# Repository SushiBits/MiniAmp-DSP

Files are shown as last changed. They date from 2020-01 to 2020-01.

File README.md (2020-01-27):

# MiniAmp DSP

Miniature Audio Amplifier with a DSP inside.

eUPID: `M2AUv3-AMP4268`

## Specifications

* Power input: DC 9-24V 6W, center positive barrel jack.
* Signal input: Unbalanced consumer line level, 3.5mm TRS jack.
* Outputs:
  * Left and Right speakers: balanced 6W class D output, screw terminals.
  * Center speaker: balanced 1W class AB output, screw terminals.
  * Subwoofer: Consumer line level, RCA coaxial.
  * Headphone: Unbalanced 6W class D output, 3.5mm TRS jack. The prescense of a
    headphone disables all other outputs.
* DSP: Analog Devices AD1701 SigmaDSP.

## Programming the DSP

This DSP is programmed using [Analog Devices SigmaStudio][1]. You need a USBi,
for example the [SigmaLink USBi][2], to program the devce.

[1]: https://www.analog.com/en/design-center/evaluation-hardware-and-software/software/ss_sigst_02.html
[2]: https://github.com/freeDSP/SigmaLink-USBi

## License & Contacts

Copyright &copy; 2019-2020 Max Chan. All rights reserved.

This project is licensed under [3-clause BSD license](LICENSE.md).

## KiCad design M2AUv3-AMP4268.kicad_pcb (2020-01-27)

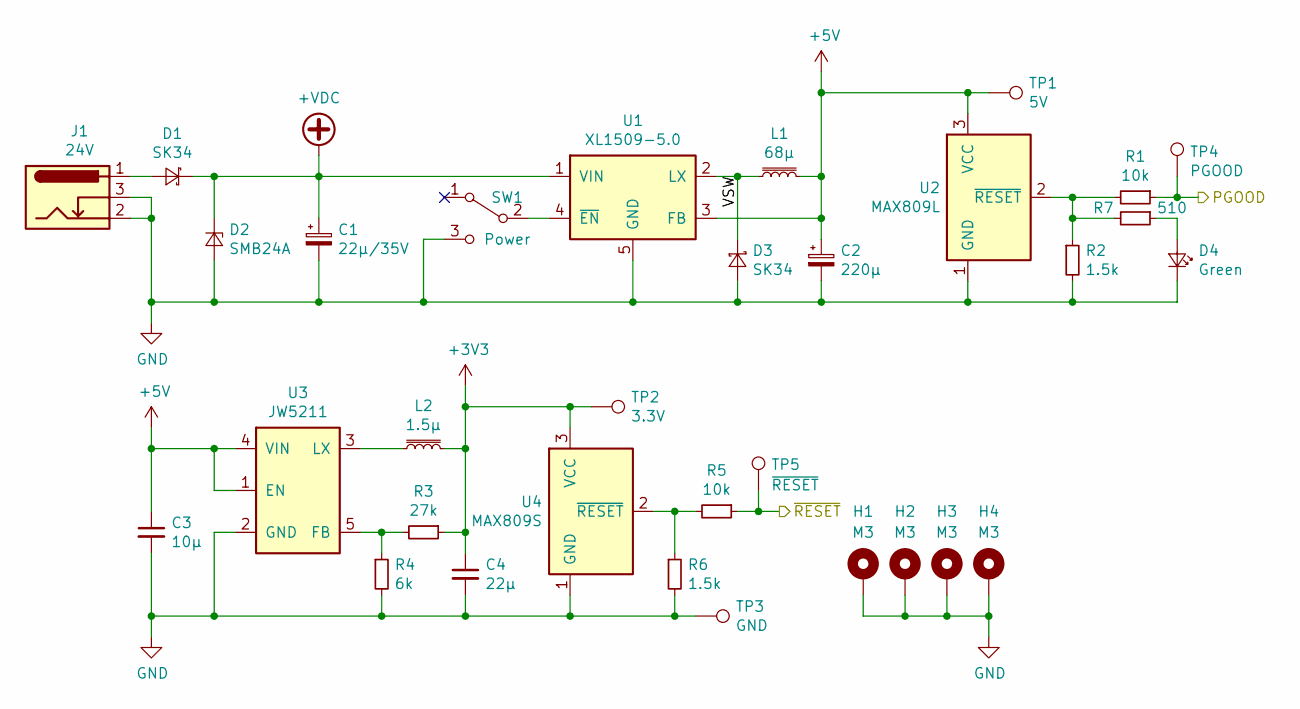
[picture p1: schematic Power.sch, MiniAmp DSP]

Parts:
C1: 22µ/35V; CP_Elec_6.3x5.4
C2: 220µ; CP_Elec_6.3x5.4
C3: 10µ; C_0805_2012Metric_Pad1.15x1.40mm_HandSolder
C4: 22µ; C_0805_2012Metric_Pad1.15x1.40mm_HandSolder
D1, D3: SK34; D_SMB
D2: SMB24A; D_SMB
D4: Green; LED_1206_3216Metric_Pad1.42x1.75mm_HandSolder
H1, H2, H3, H4: M3; MountingHole_3.2mm_M3_Pad_Via
J1: 24V; BarrelJack_Wuerth_6941xx301002
L1: 68µ; L_Taiyo-Yuden_NR-60xx_HandSoldering
L2: 1.5µ; L_0806_2016Metric_Pad1.15x1.80mm_HandSolder
R1, R5: 10k; R_0603_1608Metric_Pad1.05x0.95mm_HandSolder
R2, R6: 1.5k; R_0603_1608Metric_Pad1.05x0.95mm_HandSolder
R3: 27k; R_0603_1608Metric_Pad1.05x0.95mm_HandSolder
R4: 6k; R_0603_1608Metric_Pad1.05x0.95mm_HandSolder
R7: 510; R_0603_1608Metric_Pad1.05x0.95mm_HandSolder
SW1: Power; SW_SPDT_PCM12
TP1: 5V; TestPoint_Loop_D2.54mm_Drill1.5mm_Beaded
TP2: 3.3V; TestPoint_Loop_D2.54mm_Drill1.5mm_Beaded
TP3: GND; TestPoint_Loop_D2.54mm_Drill1.5mm_Beaded
TP4: PGOOD; TestPoint_Loop_D2.54mm_Drill1.5mm_Beaded
TP5: ~RESET; TestPoint_Loop_D2.54mm_Drill1.5mm_Beaded
U1: XL1509-5.0; SOIC-8_3.9x4.9mm_P1.27mm
U2: MAX809L; SOT-23
U3: JW5211; SOT-23-5
U4: MAX809S; SOT-23

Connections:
+3V3: C4.1, L2.2, R3.1, TP2.1, U4.3 (VCC); also elsewhere on the board
+5V: C2.1, C3.1, L1.2, TP1.1, U1.3 (FB), U2.3 (VCC), U3.1 (EN), U3.4 (VIN); also elsewhere on the board
+VDC: C1.1, D1.1 (K), D2.1 (K), U1.1 (VIN)
/DSP/~RESET: R5.1, TP5.1; also elsewhere on the board
/PGOOD: R1.1, TP4.1; also elsewhere on the board
/Power Delivery/VSW: D3.1 (K), L1.1, U1.2 (LX)
GND: C1.2, C2.2, C3.2, C4.2, D2.2 (A), D3.2 (A), D4.1 (K), H1.1, H2.1, H3.1, H4.1, J1.2, J1.3, R2.2, R4.2, R6.2, SW1.3 (C), TP3.1, U1.5 (GND), U1.6 (GND), U1.7 (GND), U1.8 (GND), U2.1 (GND), U3.2 (GND), U4.1 (GND); also elsewhere on the board
unnamed: D1.2 (A), J1.1
unnamed: D4.2 (A), R7.1
unnamed: L2.1, U3.3 (LX)
unnamed: R1.2, R2.1, R7.2, U2.2 (~RESET~)
unnamed: R3.2, R4.1, U3.5 (FB)
unnamed: R5.2, R6.1, U4.2 (~RESET~)
unnamed: SW1.2 (B), U1.4 (~EN)

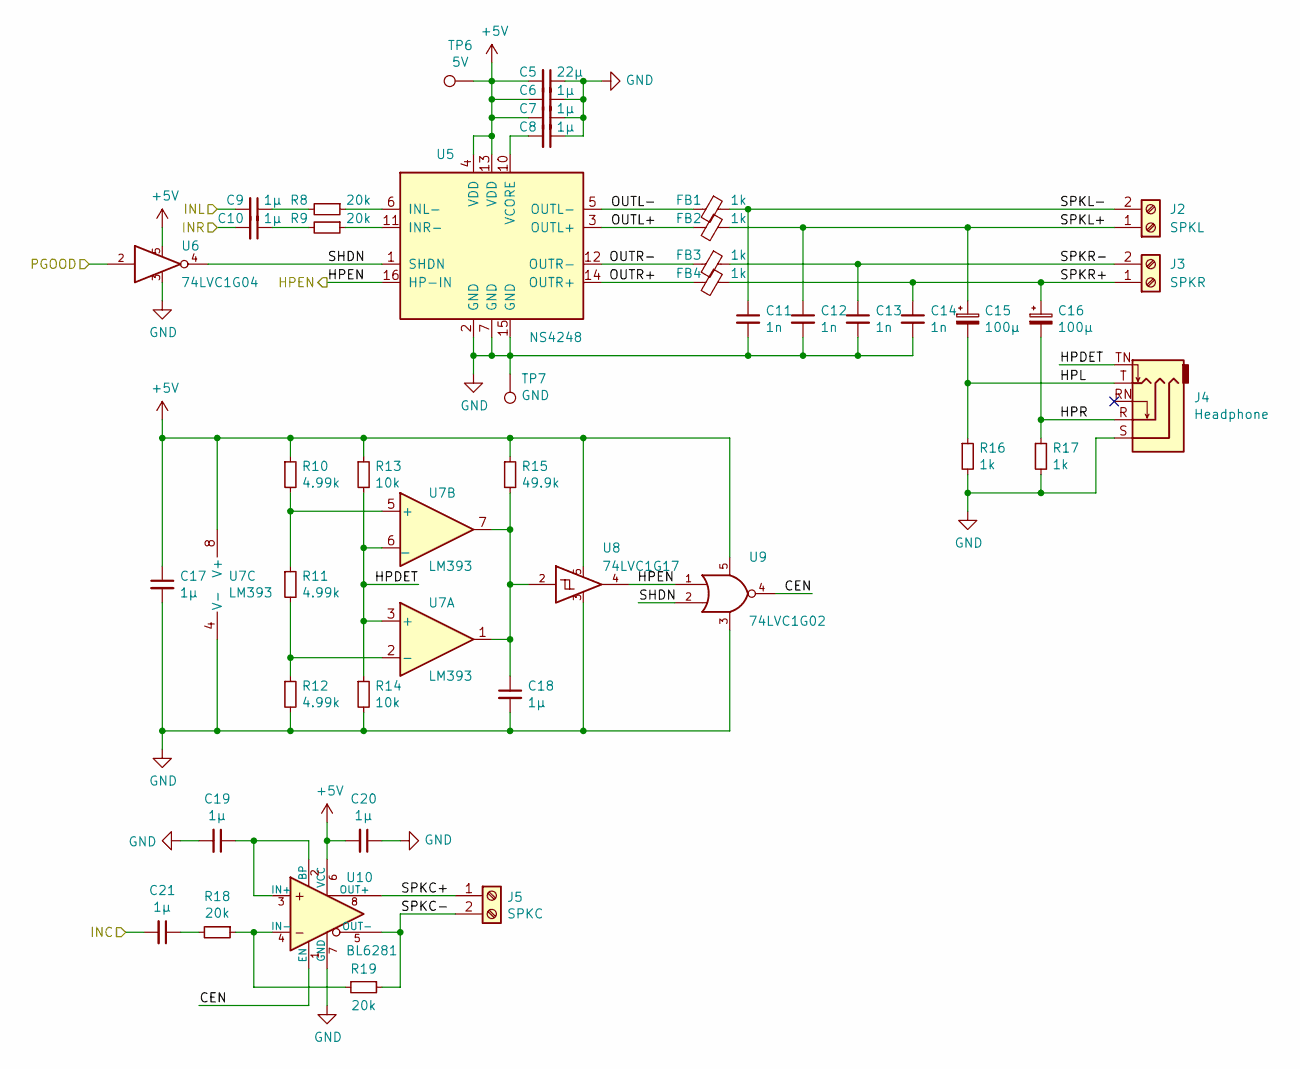
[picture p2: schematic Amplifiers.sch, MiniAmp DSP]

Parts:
C5: 22µ; C_0805_2012Metric_Pad1.15x1.40mm_HandSolder
C6, C7, C8, C9, C10, C17, C18, C19, C20, C21: 1µ; C_0603_1608Metric_Pad1.05x0.95mm_HandSolder
C11, C12, C13, C14: 1n; C_0603_1608Metric_Pad1.05x0.95mm_HandSolder
C15, C16: 100µ; CP_EIA-3528-21_Kemet-B_Pad1.50x2.35mm_HandSolder
FB1, FB2, FB3, FB4: 1k; L_0603_1608Metric_Pad1.05x0.95mm_HandSolder
J2: SPKL; TerminalBlock_Phoenix_MKDS-3-2-5.08_1x02_P5.08mm_Horizontal
J3: SPKR; TerminalBlock_Phoenix_MKDS-3-2-5.08_1x02_P5.08mm_Horizontal
J4: Headphone; Jack_3.5mm_Ledino_KB3SPRS_Horizontal
J5: SPKC; TerminalBlock_Phoenix_MKDS-3-2-5.08_1x02_P5.08mm_Horizontal
R8, R9, R18, R19: 20k; R_0603_1608Metric_Pad1.05x0.95mm_HandSolder
R10, R11, R12: 4.99k; R_0603_1608Metric_Pad1.05x0.95mm_HandSolder
R13, R14: 10k; R_0603_1608Metric_Pad1.05x0.95mm_HandSolder
R15: 49.9k; R_0603_1608Metric_Pad1.05x0.95mm_HandSolder
R16, R17: 1k; R_0603_1608Metric_Pad1.05x0.95mm_HandSolder
TP6: 5V; TestPoint_Loop_D2.54mm_Drill1.5mm_Beaded
TP7: GND; TestPoint_Loop_D2.54mm_Drill1.5mm_Beaded
U5: NS4248; SOIC-16_3.9x9.9mm_P1.27mm
U6: 74LVC1G04; SOT-23-5
U7: LM393; SOIC-8_3.9x4.9mm_P1.27mm
U8: 74LVC1G17; SOT-23-5
U9: 74LVC1G02; SOT-23-5
U10: BL6281; SOIC-8_3.9x4.9mm_P1.27mm

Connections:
+5V: C5.2, C6.2, C7.2, C17.1, C20.2, R10.1, R13.1, R15.1, TP6.1, U5.4 (VDD), U5.13 (VDD), U6.5, U7.8 (V+), U8.5, U9.5 (VCC), U10.6 (VCC); also elsewhere on the board
/Amplified Output/CEN: U9.4, U10.1 (EN)
/Amplified Output/HPDET: J4.TN, R13.2, R14.1, U7.3 (+), U7.6 (_)
/Amplified Output/HPEN: U5.16 (HP-IN), U8.4, U9.1; also elsewhere on the board
/Amplified Output/HPL: C15.2, J4.T, R16.1
/Amplified Output/HPR: C16.2, J4.R, R17.1
/Amplified Output/INC: C21.2; also elsewhere on the board
/Amplified Output/INL: C9.2; also elsewhere on the board
/Amplified Output/INR: C10.2; also elsewhere on the board
/Amplified Output/OUTL+: FB2.2, U5.3 (OUTL+)
/Amplified Output/OUTL-: FB1.2, U5.5 (OUTL-)
/Amplified Output/OUTR+: FB4.2, U5.14 (OUTR+)
/Amplified Output/OUTR-: FB3.2, U5.12 (OUTR-)
/Amplified Output/SHDN: U5.1 (SHDN), U6.4, U9.2
/Amplified Output/SPKC+: J5.1, U10.8 (OUT+)
/Amplified Output/SPKC-: J5.2, R19.1, U10.5 (OUT-)
/Amplified Output/SPKL+: C12.1, C15.1, FB2.1, J2.1
/Amplified Output/SPKL-: C11.1, FB1.1, J2.2
/Amplified Output/SPKR+: C14.1, C16.1, FB4.1, J3.1
/Amplified Output/SPKR-: C13.1, FB3.1, J3.2
/PGOOD: U6.2; also elsewhere on the board
GND: C5.1, C6.1, C7.1, C8.1, C11.2, C12.2, C13.2, C14.2, C17.2, C18.2, C19.2, C20.1, J4.S, R12.2, R14.2, R16.2, R17.2, TP7.1, U5.2 (GND), U5.7 (GND), U5.15 (GND), U6.3, U7.4 (V-), U8.3, U9.3 (GND), U10.7 (GND); also elsewhere on the board
unnamed: C8.2, U5.10 (VCORE)
unnamed: C9.1, R8.2
unnamed: C10.1, R9.2
unnamed: C18.1, R15.2, U7.1, U7.7, U8.2
unnamed: C19.1, U10.2 (BP), U10.3 (IN+)
unnamed: C21.1, R18.2
unnamed: R8.1, U5.6 (INL-)
unnamed: R9.1, U5.11 (INR-)
unnamed: R10.2, R11.1, U7.5 (+)
unnamed: R11.2, R12.1, U7.2 (-)
unnamed: R18.1, R19.2, U10.4 (IN-)

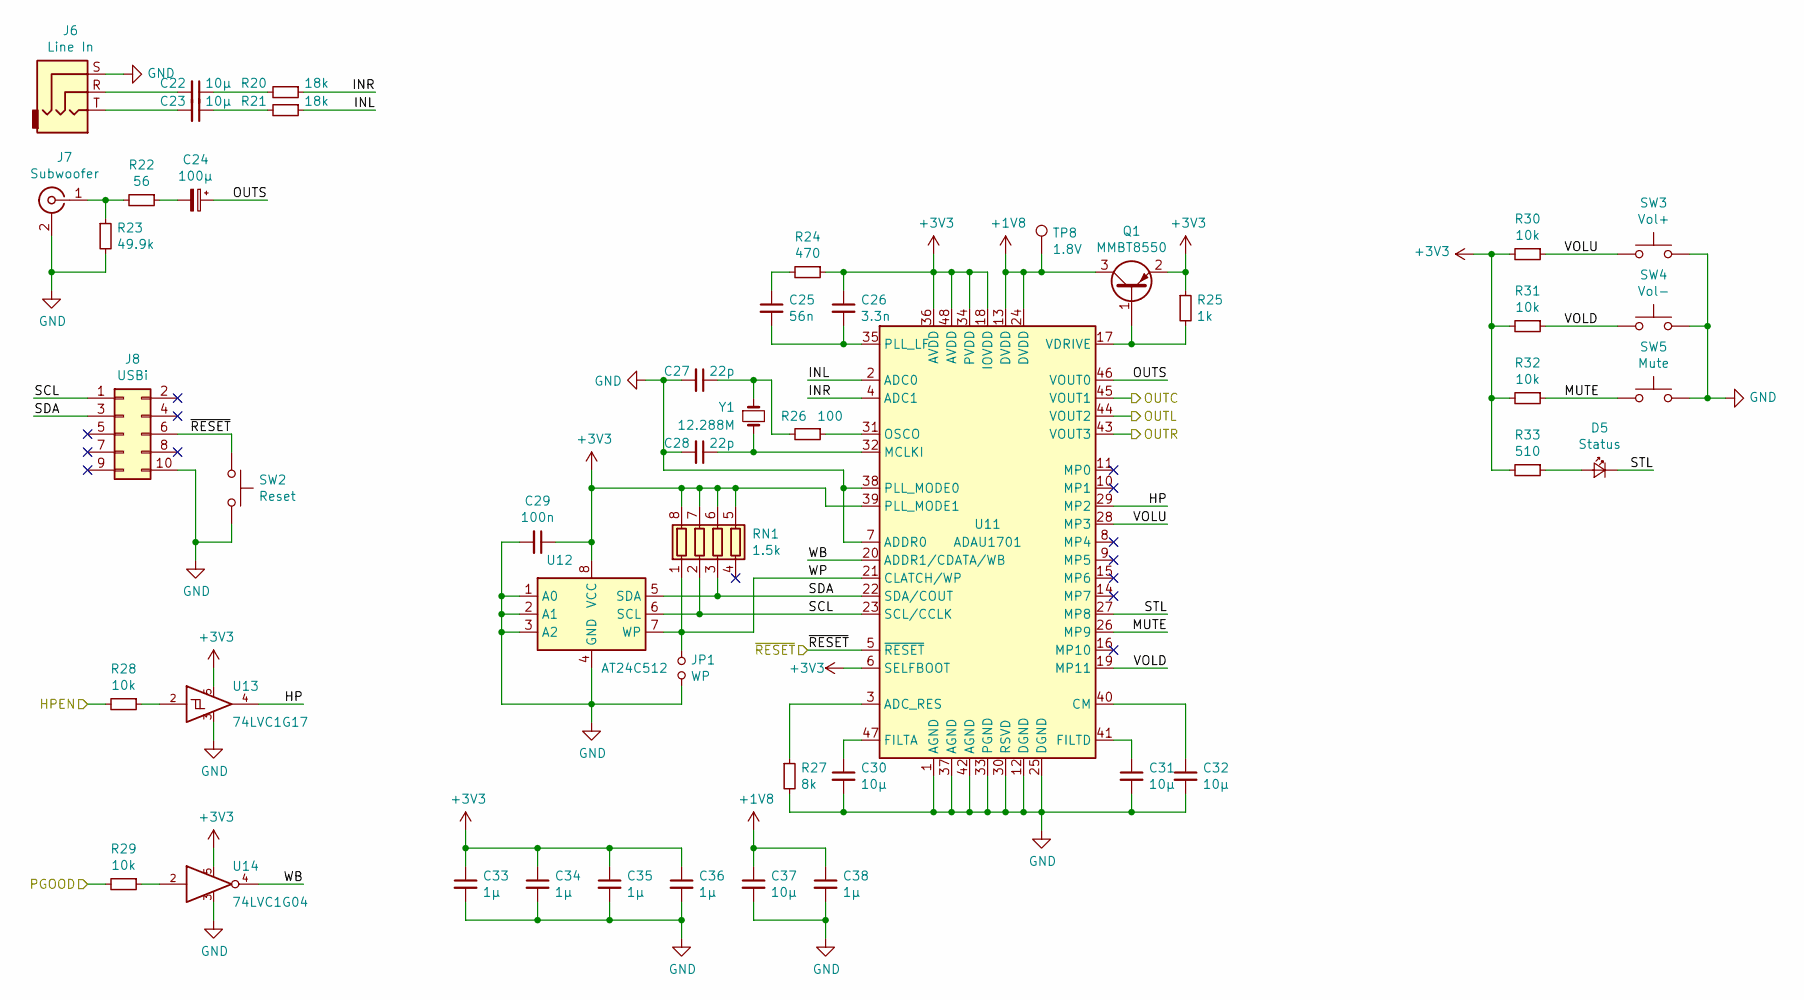
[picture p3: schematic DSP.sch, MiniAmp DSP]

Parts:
C22, C23, C30, C31, C32, C37: 10µ; C_0603_1608Metric_Pad1.05x0.95mm_HandSolder
C24: 100µ; CP_EIA-3528-21_Kemet-B_Pad1.50x2.35mm_HandSolder
C25: 56n; C_0603_1608Metric_Pad1.05x0.95mm_HandSolder
C26: 3.3n; C_0603_1608Metric_Pad1.05x0.95mm_HandSolder
C27, C28: 22p; C_0603_1608Metric_Pad1.05x0.95mm_HandSolder
C29: 100n; C_0603_1608Metric_Pad1.05x0.95mm_HandSolder
C33, C34, C35, C36, C38: 1µ; C_0603_1608Metric_Pad1.05x0.95mm_HandSolder
D5: Status; LED_1206_3216Metric_Pad1.42x1.75mm_HandSolder
J6: Line In; PJ3130
J7: Subwoofer; RCA
J8: USBi; IDC-Header_2x05_P2.54mm_Vertical
JP1: WP; PinHeader_2x01_P2.00mm_Vertical
Q1: MMBT8550; SOT-23
R20, R21: 18k; R_0603_1608Metric_Pad1.05x0.95mm_HandSolder
R22: 56; R_0603_1608Metric_Pad1.05x0.95mm_HandSolder
R23: 49.9k; R_0603_1608Metric_Pad1.05x0.95mm_HandSolder
R24: 470; R_0603_1608Metric_Pad1.05x0.95mm_HandSolder
R25: 1k; R_0603_1608Metric_Pad1.05x0.95mm_HandSolder
R26: 100; R_0603_1608Metric_Pad1.05x0.95mm_HandSolder
R27: 8k; R_0603_1608Metric_Pad1.05x0.95mm_HandSolder
R28, R29, R30, R31, R32: 10k; R_0603_1608Metric_Pad1.05x0.95mm_HandSolder
R33: 510; R_0603_1608Metric_Pad1.05x0.95mm_HandSolder
RN1: 1.5k; R_Array_Concave_4x0603
SW2: Reset; SW_SPST_1TS003B-0A
SW3: Vol+; SW_SPST_1TS003B-0A
SW4: Vol-; SW_SPST_1TS003B-0A
SW5: Mute; SW_SPST_1TS003B-0A
TP8: 1.8V; TestPoint_Loop_D2.54mm_Drill1.5mm_Beaded
U11: ADAU1701; LQFP-48_7x7mm_P0.5mm
U12: AT24C512; SOIC-8_3.9x4.9mm_P1.27mm
U13: 74LVC1G17; SOT-23-5
U14: 74LVC1G04; SOT-23-5
Y1: 12.288M; Crystal_SMD_5032-2Pin_5.0x3.2mm

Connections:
+1V8: C37.1, C38.1, Q1.3 (C), TP8.1, U11.13 (DVDD), U11.24 (DVDD)
+3V3: C26.1, C29.1, C33.1, C34.1, C35.1, C36.1, Q1.2 (E), R24.1, R25.1, R30.2, R31.2, R32.2, R33.2, RN1.5 (R4.2), RN1.6 (R3.2), RN1.7 (R2.2), RN1.8 (R1.2), U11.6 (SELFBOOT), U11.18 (IOVDD), U11.34 (PVDD), U11.36 (AVDD), U11.39 (PLL_MODE1), U11.48 (AVDD), U12.8 (VCC), U13.5, U14.5; also elsewhere on the board
/Amplified Output/HPEN: R28.2; also elsewhere on the board
/Amplified Output/INC: U11.45 (VOUT1); also elsewhere on the board
/Amplified Output/INL: U11.44 (VOUT2); also elsewhere on the board
/Amplified Output/INR: U11.43 (VOUT3); also elsewhere on the board
/DSP/HP: U11.29 (MP2), U13.4
/DSP/INL: R21.1, U11.2 (ADC0)
/DSP/INR: R20.1, U11.4 (ADC1)
/DSP/MUTE: R32.1, SW5.1, U11.26 (MP9)
/DSP/OUTS: C24.1, U11.46 (VOUT0)
/DSP/SCL: J8.1, RN1.2 (R2.1), U11.23 (SCL/CCLK), U12.6 (SCL)
/DSP/SDA: J8.3, RN1.3 (R3.1), U11.22 (SDA/COUT), U12.5 (SDA)
/DSP/STL: D5.1 (K), U11.27 (MP8)
/DSP/VOLD: R31.1, SW4.1, U11.19 (MP11)
/DSP/VOLU: R30.1, SW3.1, U11.28 (MP3)
/DSP/WB: U11.20 (ADDR1/CDATA/WB), U14.4
/DSP/WP: JP1.1, RN1.1 (R1.1), U11.21 (CLATCH/WP), U12.7 (WP)
/DSP/~RESET: J8.6, SW2.2, U11.5 (~RESET); also elsewhere on the board
/PGOOD: R29.2; also elsewhere on the board
GND: C27.2, C28.2, C29.2, C30.2, C31.2, C32.2, C33.2, C34.2, C35.2, C36.2, C37.2, C38.2, J6.S, J7.2 (Ext), J8.10, JP1.2, R23.2, R27.2, SW2.1, SW3.2, SW4.2, SW5.2, U11.1 (AGND), U11.7 (ADDR0), U11.12 (DGND), U11.25 (DGND), U11.30 (RSVD), U11.33 (PGND), U11.37 (AGND), U11.38 (PLL_MODE0), U11.42 (AGND), U12.1 (A0), U12.2 (A1), U12.3 (A2), U12.4 (GND), U13.3, U14.3; also elsewhere on the board
unnamed: C22.1, R20.2
unnamed: C22.2, J6.R
unnamed: C23.1, R21.2
unnamed: C23.2, J6.T
unnamed: C24.2, R22.1
unnamed: C25.1, R24.2
unnamed: C25.2, C26.2, U11.35 (PLL_LF)
unnamed: C27.1, R26.2, Y1.1
unnamed: C28.1, U11.32 (MCLKI), Y1.2
unnamed: C30.1, U11.47 (FILTA)
unnamed: C31.1, U11.41 (FILTD)
unnamed: C32.1, U11.40 (CM)
unnamed: D5.2 (A), R33.1
unnamed: J7.1 (In), R22.2, R23.1
unnamed: Q1.1 (B), R25.2, U11.17 (VDRIVE)
unnamed: R26.1, U11.31 (OSCO)
unnamed: R27.1, U11.3 (ADC_RES)
unnamed: R28.1, U13.2
unnamed: R29.1, U14.2

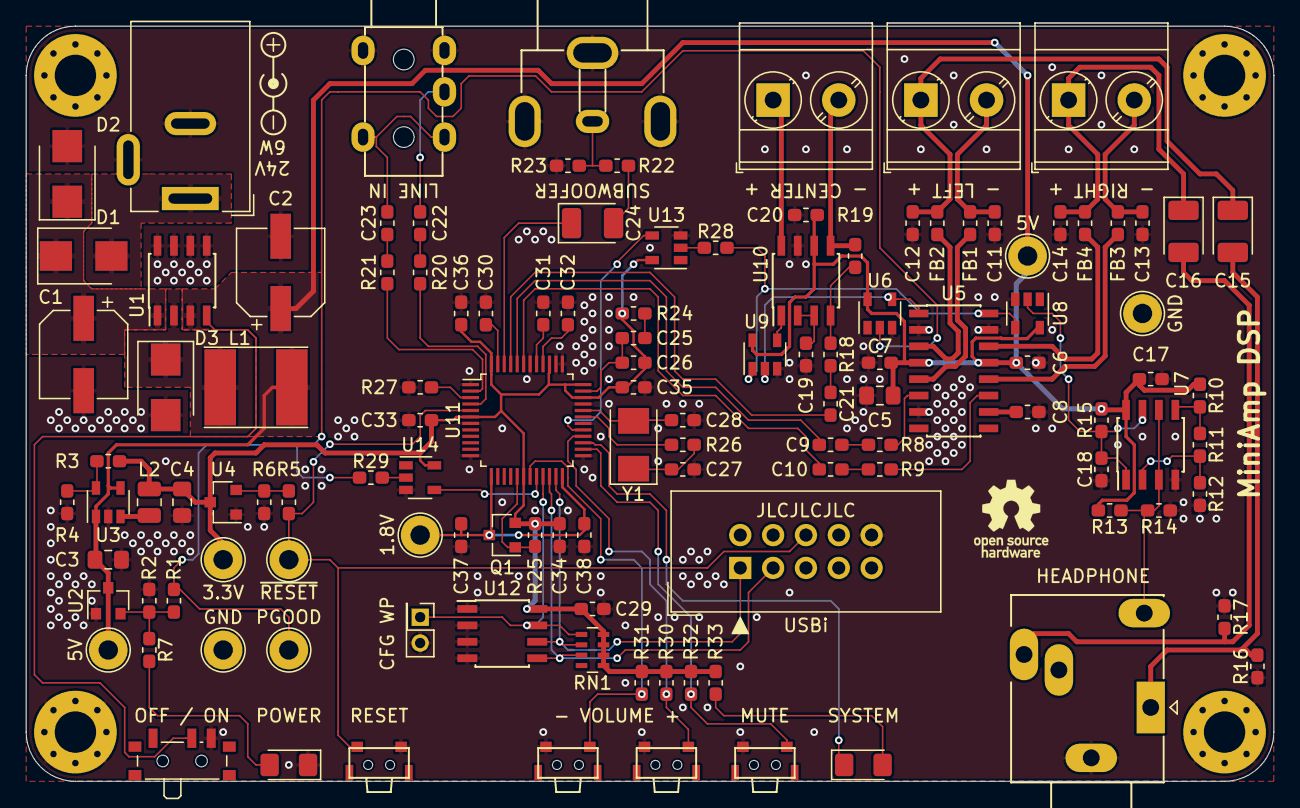
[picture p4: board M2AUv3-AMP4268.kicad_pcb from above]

Board: 2 copper layers, 96.5 x 58.4 mm, 125 parts (0 on the bottom side), 76 nets.
